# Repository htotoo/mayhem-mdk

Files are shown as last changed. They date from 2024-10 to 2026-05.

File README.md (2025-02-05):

# PortaPack Mayhem External Module Developer Kit "MDK"
This is the Developer Kit External Module for the [HackRF+PortaPack H4](https://github.com/portapack-mayhem/mayhem-firmware)

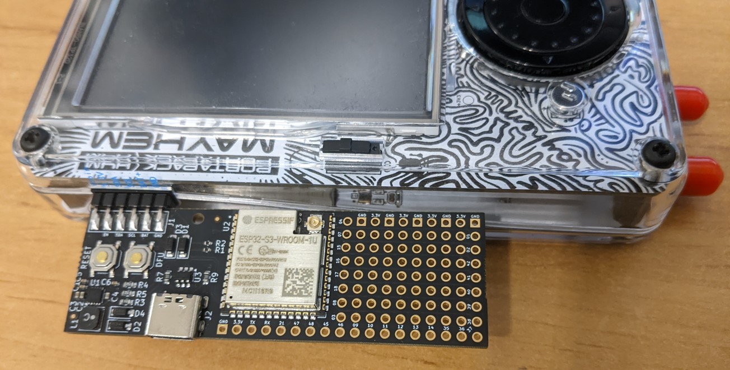
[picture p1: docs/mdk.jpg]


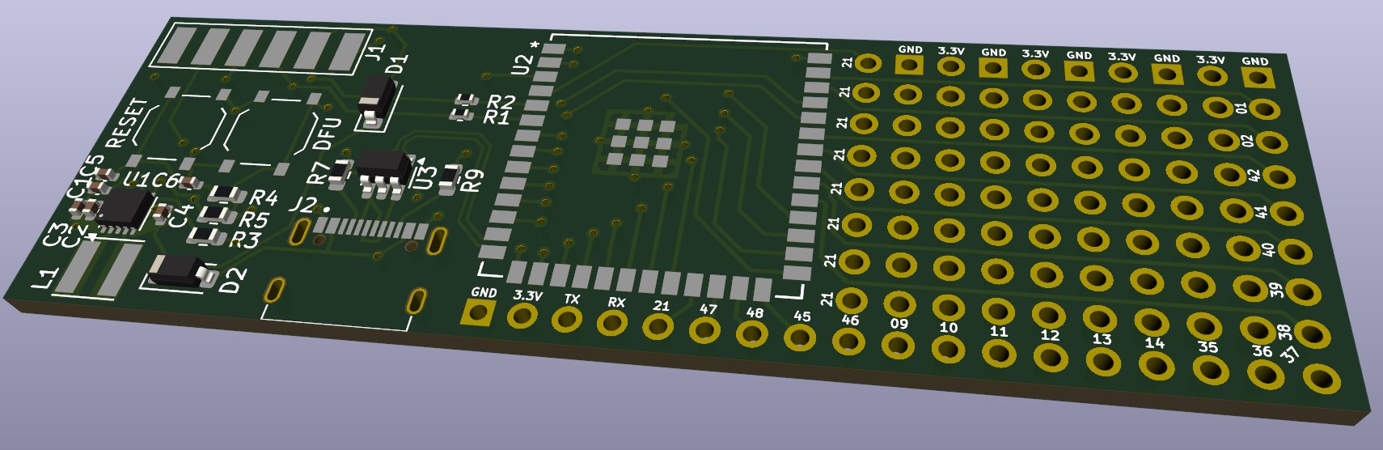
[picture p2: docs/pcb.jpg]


## How to get the hardware
All the design files are in the pcb folder. They are set up so you can let [JLCPCB](https://jlcpcb.com/) manufacture a few boards by using the files in pcb/production.

## How to compile
The software consists of two separate parts:
- The Standalone App that is uploaded and executed on the portapack.
  - This will be embedded in the the ESP32 firmware, so is required first.
  - The guide can be found [here](src/uart/Readme.md)
- The firmware for the ESP32-S3.
  - The guide can be found [here](src/portapack-external-module/README.md) 
  - Note: ESP-IDF version 5.4 introduced a breaking change in the I2C subsystem. So use the latest version of 5.3.

## How to use the example UART app
Once the Firmware is uploaded and the module is plugged into the Portapack, the UART app should appear in the Utilities menu.

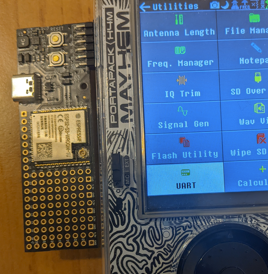
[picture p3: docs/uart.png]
uart app


The UART app will display any UART signal on pin 14.

## Schematics
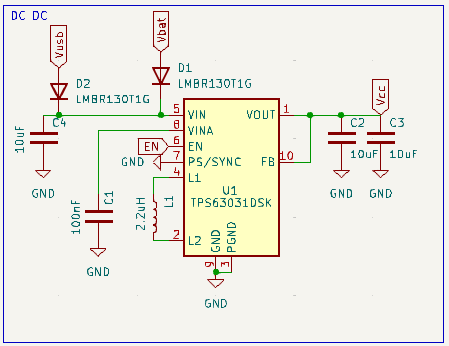
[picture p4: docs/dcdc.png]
dcdc


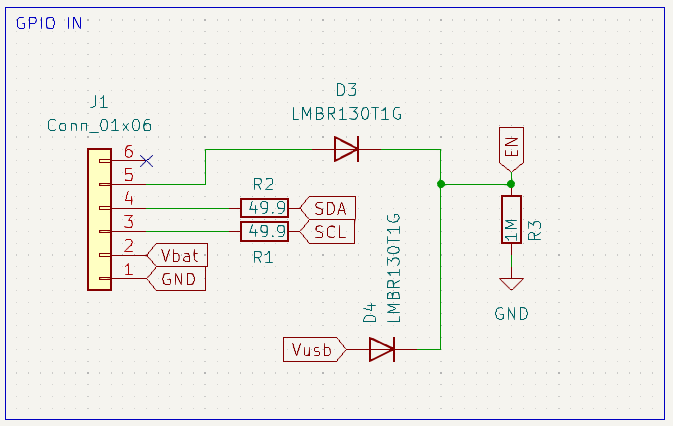
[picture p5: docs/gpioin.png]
gpioin


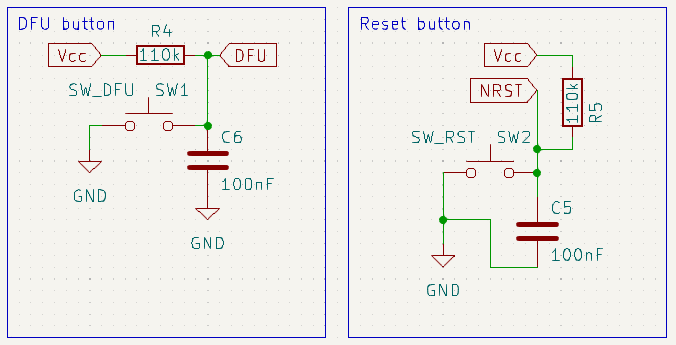
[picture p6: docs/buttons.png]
buttons


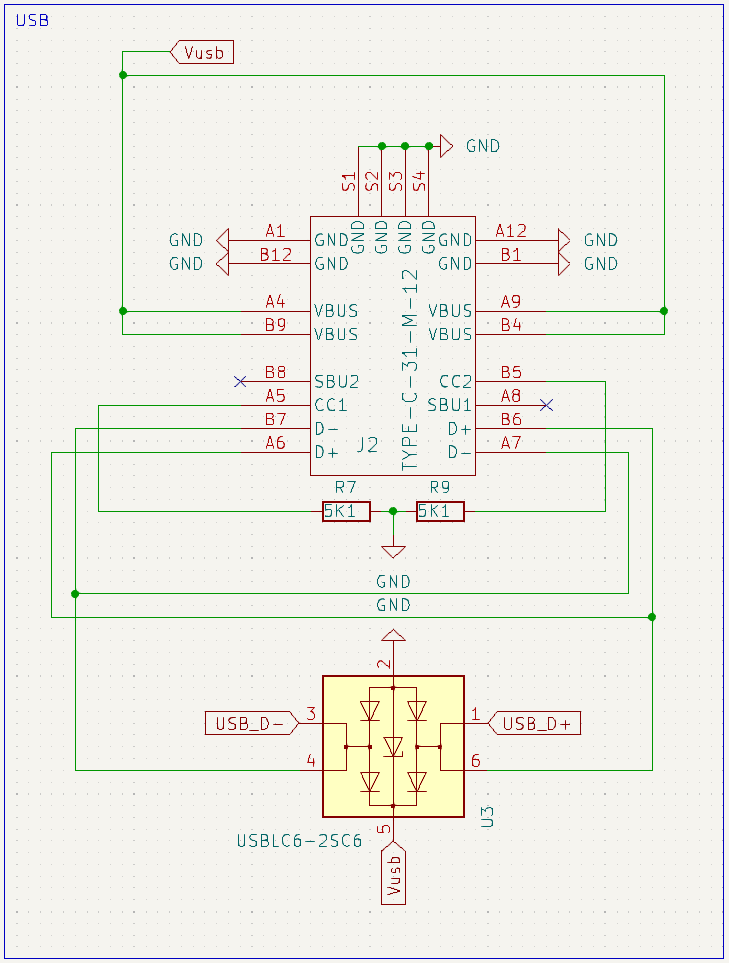
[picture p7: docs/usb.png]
usb


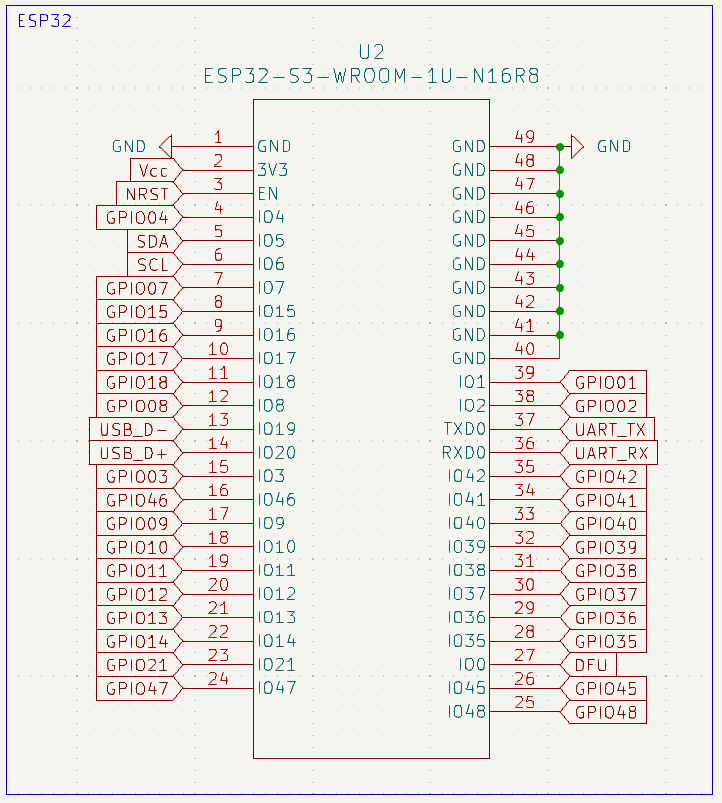
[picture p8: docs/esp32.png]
esp32


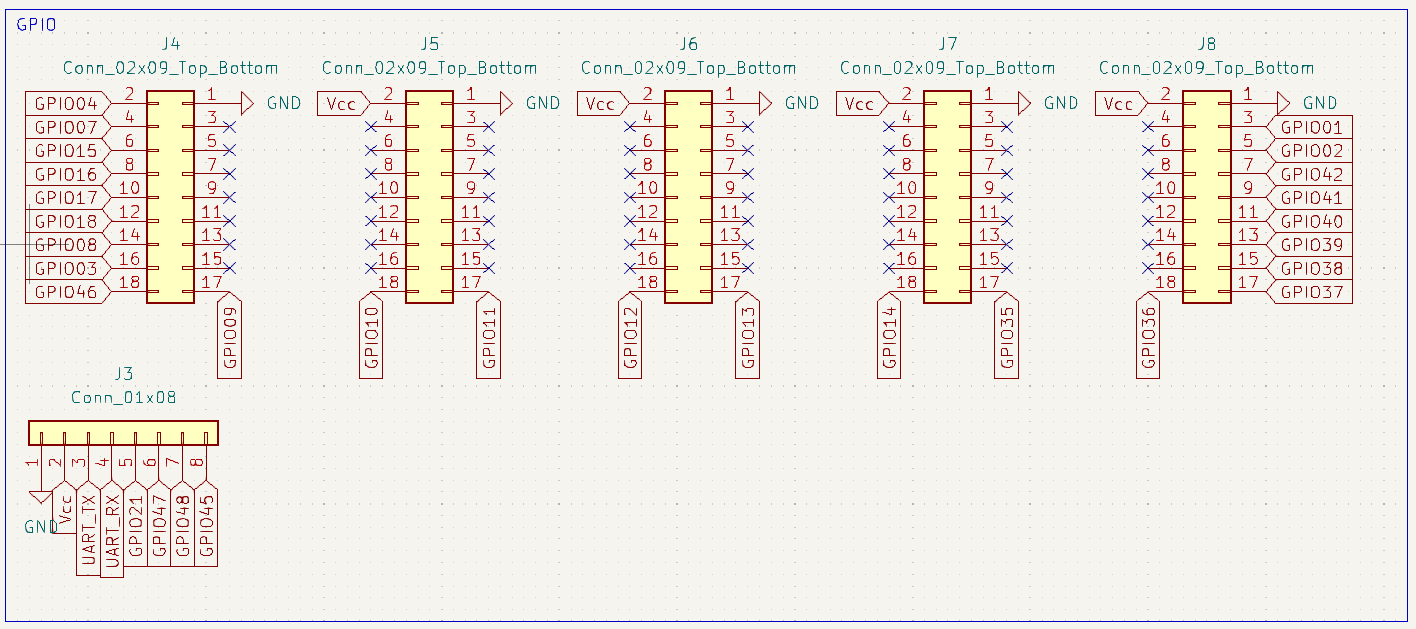
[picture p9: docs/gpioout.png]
gpioout


## Pinout
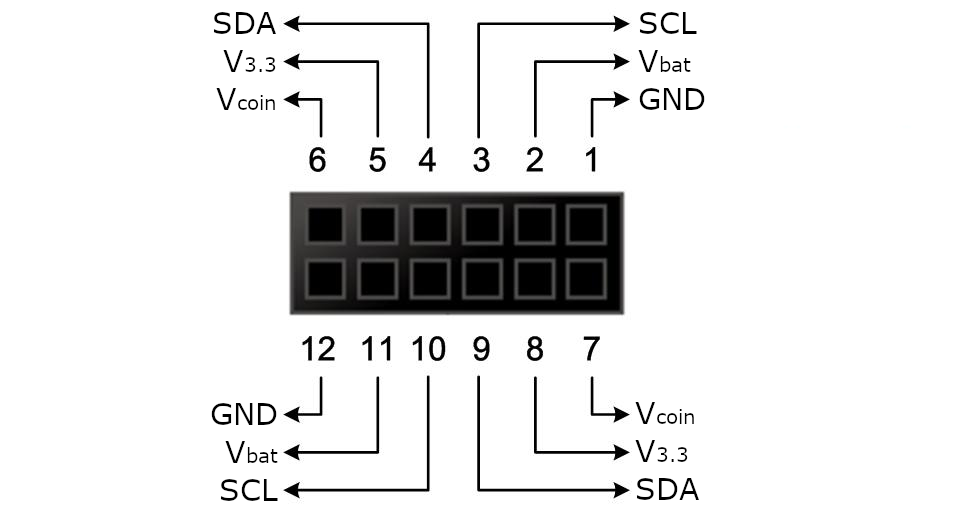
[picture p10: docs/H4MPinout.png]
pinout


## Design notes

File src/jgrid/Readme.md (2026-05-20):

# jgrid

This is a joke app that simulates "hacking" Grids (like power grids), and can power down nuclear plans.

It is only for fun and parody.

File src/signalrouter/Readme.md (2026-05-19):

# Signal router

The TX must wired to RX

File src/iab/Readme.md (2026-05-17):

# iab

Idle miner app, when you drill down, while each level is harder, so you'll need to buy upgrades.

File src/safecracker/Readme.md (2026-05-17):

# Safecracker game

Crack the safe by selecting the correct code for each slot. Time is ticking, and the signal is getting weaker and weaker.

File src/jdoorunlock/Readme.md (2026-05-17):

# jdoorunlock

This is a joke app that simulates "hacking" door locks and unlocking any door wirelessly.

It is only for fun and parody.

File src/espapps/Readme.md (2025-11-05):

# App manager for ESP32PP

# to build

cmake -DCMAKE_TOOLCHAIN_FILE=arm-none-eabi-toolchain.cmake -B build -S.
make -C build espapps

# build with docker
docker build -t arm-docker-build config
docker run --rm -v .:/src -w /src arm-docker-build bash -c "cmake -DCMAKE_TOOLCHAIN_FILE=config/arm-none-eabi-toolchain.cmake -B build -S."
docker run --rm -v .:/src -w /src arm-docker-build bash -c "make -C build -j3"

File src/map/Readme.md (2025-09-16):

# A test app to check if map ui is working in the standalone apps. 
Not used anywhere, just a test app

# Requirements
Like the mayhem-firmware a version of gcc-arm-none-eabi is required. See [Compile Firmware](https://github.com/portapack-mayhem/mayhem-firmware/wiki/Compile-firmware) on how to get started.

# to build

cmake -DCMAKE_TOOLCHAIN_FILE=../common/config/arm-none-eabi-toolchain.cmake -B build -S.
make -C build

# build with docker
docker build -t arm-docker-build ../common/config
docker run --rm -v .:/src -w /src arm-docker-build bash -c "cmake -DCMAKE_TOOLCHAIN_FILE=common/config/arm-none-eabi-toolchain.cmake -B build -S."
docker run --rm -v .:/src -w /src arm-docker-build bash -c "make -C build -j3"

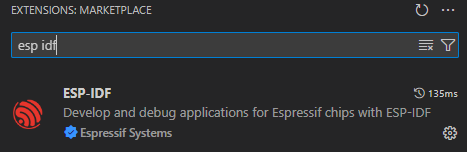
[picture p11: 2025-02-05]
src/portapack-external-module/espidf.png

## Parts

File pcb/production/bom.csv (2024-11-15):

Designator | Footprint | Quantity | Value | LCSC Part #
C1_5, C1_4, C1_3, C1_2, C1, C5_5, C5_4, C5_3, C5_2, C5, C6_5, C6_4, C6_3, C6_2, C6 | 0402 | 15 | 100nF | C1525
C2_5, C2_4, C2_3, C2_2, C2, C3_5, C3_4, C3_3, C3_2, C3, C4_5, C4_4, C4_3, C4_2, C4 | 0402 | 15 | 10uF | C15525
D1_5, D1_4, D1_3, D1_2, D1, D2_5, D2_4, D2_3, D2_2, D2, D3_5, D3_4, D3_3, D3_2, D3, D4_5, D4_4, D4_3, D4_2, D4 | D_SOD-123 | 20 | LMBR130T1G | C48974
J2_5, J2_4, J2_3, J2_2, J2 | TYPE-C-31-M-12 | 5 | TYPE-C-31-M-12 | C165948
L1_5, L1_4, L1_3, L1_2, L1 | L_Taiyo-Yuden_NR-40xx | 5 | 2.2uH | C515383
R1_5, R1_4, R1_3, R1_2, R1, R2_5, R2_4, R2_3, R2_2, R2 | 0402 | 10 | 49.9 | C25120
R3_5, R3_4, R3_3, R3_2, R3 | 0603 | 5 | 1M | C22935
R4_5, R4_4, R4_3, R4_2, R4, R5_5, R5_4, R5_3, R5_2, R5 | 0603 | 10 | 110k | C25805
R7_5, R7_4, R7_3, R7_2, R7, R9_5, R9_4, R9_3, R9_2, R9 | 0603 | 10 | 5K1 | C23186
SW1_5, SW1_4, SW1_3, SW1_2, SW1 | SW_Push_1P1T_XKB_TS-1187A | 5 | SW_DFU | C318884
SW2_5, SW2_4, SW2_3, SW2_2, SW2 | SW_Push_1P1T_XKB_TS-1187A | 5 | SW_RST | C318884
U1_5, U1_4, U1_3, U1_2, U1 | WSON-10-1EP_2.5x2.5mm_P0.5mm_EP1.2x2mm | 5 | TPS63031DSK | C15516
U2_5, U2_4, U2_3, U2_2, U2 | ESP32-S3-WROOM-1U_EXP | 5 | ESP32-S3-WROOM-1U-N16R8 | C3013946
U3_5, U3_4, U3_3, U3_2, U3 | SOT-23-6 | 5 | USBLC6-2SC6 | C2827654

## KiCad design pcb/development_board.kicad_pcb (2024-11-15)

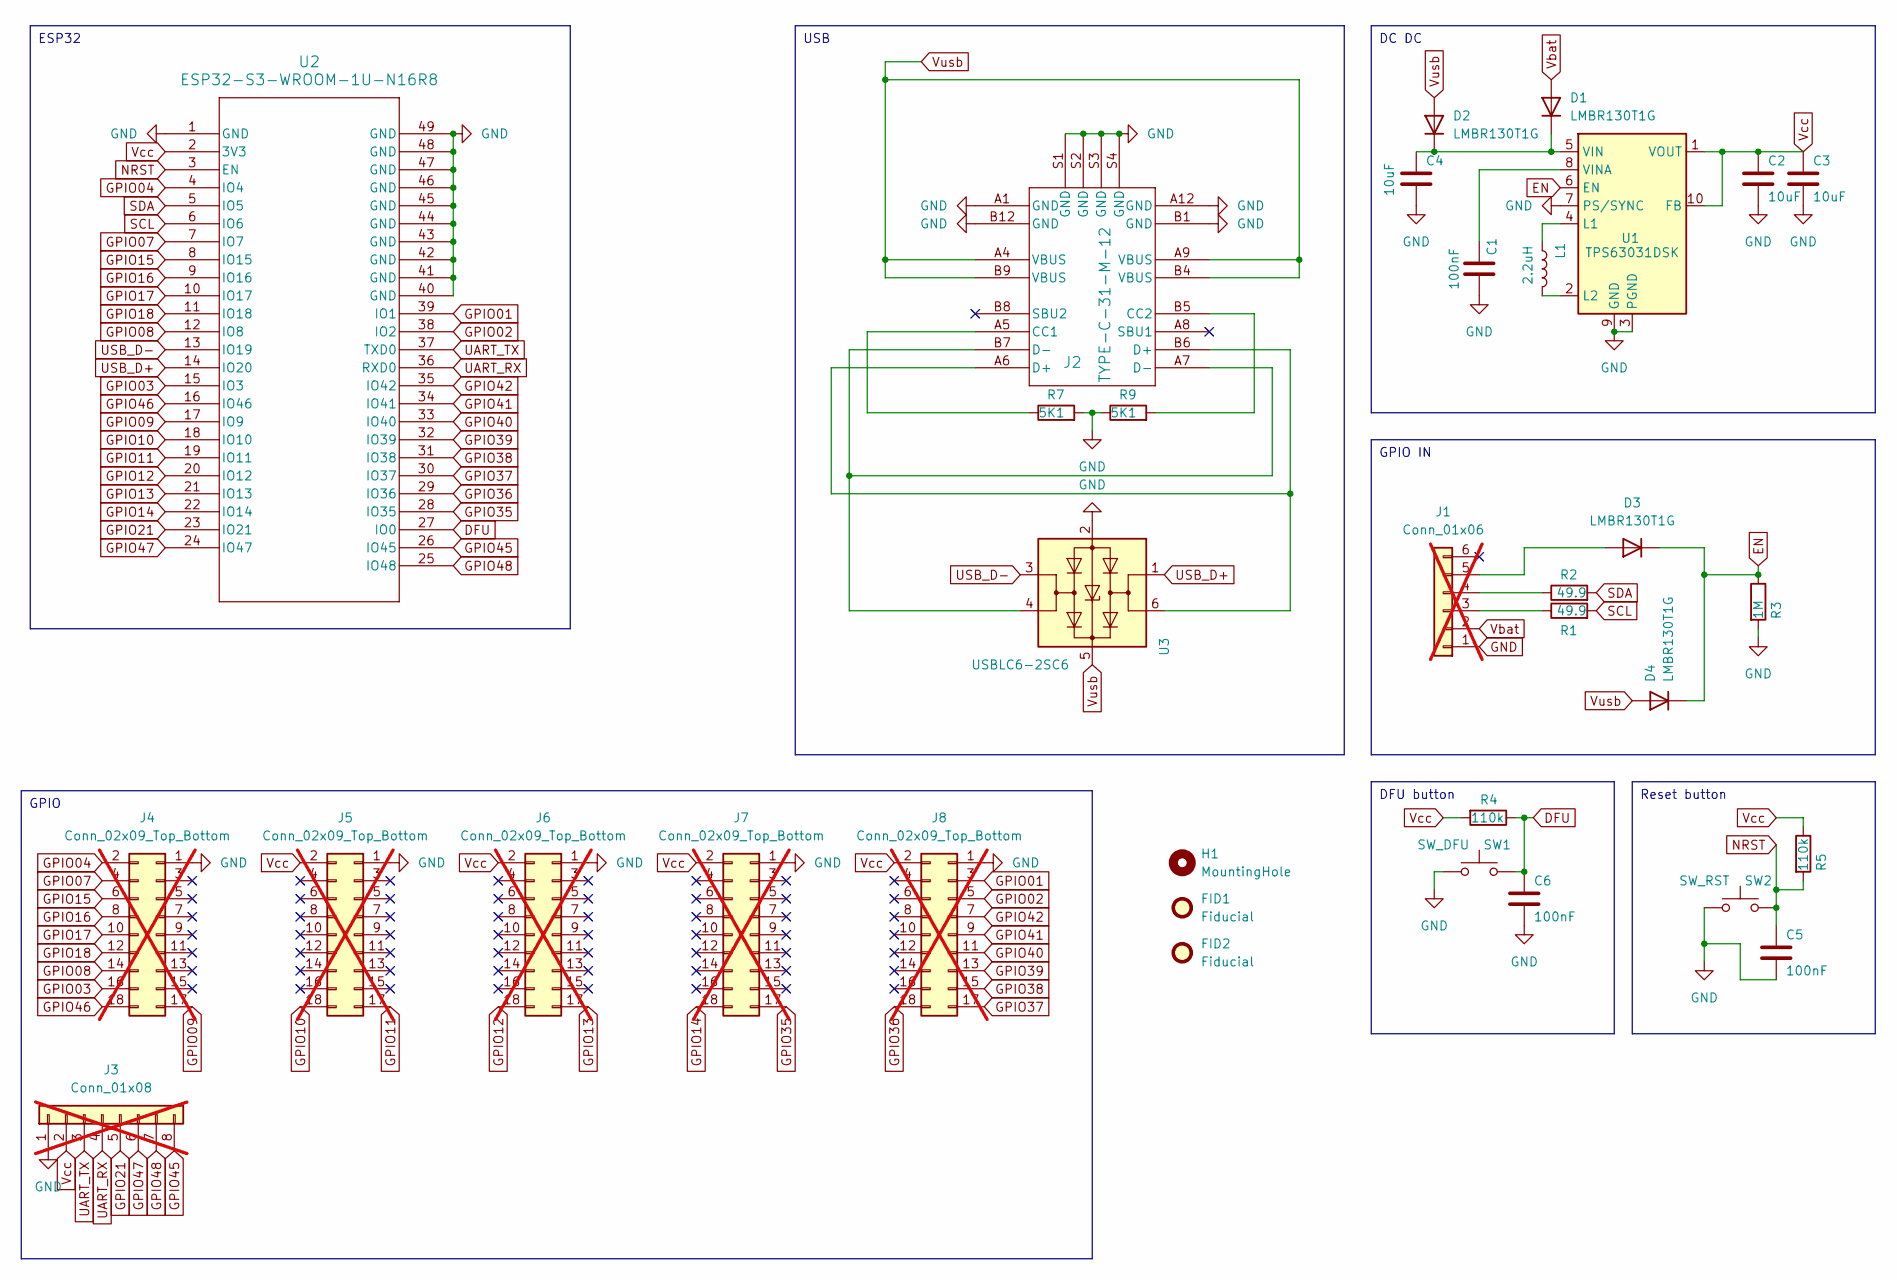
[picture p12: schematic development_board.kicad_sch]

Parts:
C1, C5, C6: 100nF; C_0402_1005Metric; Part CL05B104KO5NNNC; JLC 0402
C2, C3, C4: 10uF; C_0402_1005Metric; Part CL05A106MQ5NUNC; JLC 0402
D1, D2, D3, D4: LMBR130T1G; D_SOD-123; Part LMBR130T1G; JLC SOD-123
FID1, FID2: Fiducial; Fiducial_0.75mm_Mask1.5mm
H1: MountingHole; MountingHole_2mm
J1: Conn_01x06; External Module; not fitted
J2: TYPE-C-31-M-12; JLC SMD
J3: Conn_01x08; PinSocket_1x08_P2.54mm_Vertical; not fitted
J4, J5, J6, J7, J8: Conn_02x09_Top_Bottom; PinSocket_2x09_P2.54mm_Vertical; not fitted
L1: 2.2uH; L_Taiyo-Yuden_NR-40xx; Part NRS4010T2R2MDGGV; JLC SMD,4x4mm
R1, R2: 49.9; R_0402_1005Metric; Part 0402WGF499JTCE; JLC 0402
R3: 1M; R_0603_1608Metric; Part 0603WAF1004T5E; JLC 0603
R4, R5: 110k; R_0603_1608Metric; Part 0603WAF1103T5E; JLC 0603
R7, R9: 5K1; R_0603_1608Metric; Part 0603WAF5101T5E; JLC 0603
SW1: SW_DFU; SW_Push_1P1T_XKB_TS-1187A; Part TS-1187A-B-A-B; JLC SMD
SW2: SW_RST; SW_Push_1P1T_XKB_TS-1187A; Part TS-1187A-B-A-B; JLC SMD
U1: TPS63031DSK; WSON-10-1EP_2.5x2.5mm_P0.5mm_EP1.2x2mm; Part TPS63031DSKR; JLC SON-10-EP(2.5x2.5)
U2: ESP32-S3-WROOM-1U-N16R8; ESP32­S3­WROOM­1U_EXP; Part ESP32-S3-WROOM-1U-N16R8; JLC SMD,18x19.2mm
U3: USBLC6-2SC6; SOT-23-6; Part USBLC6-2SC6; JLC SOT-23-6

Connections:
DFU: C6.1, R4.1, SW1.2, U2.27 (IO0)
EN: D3.1 (K), D4.1 (K), R3.1, U1.6 (EN)
GND: C1.2, C2.2, C3.2, C4.2, C5.2, C6.2, J1.1, J2.A1 (GND), J2.A12 (GND), J2.B1 (GND), J2.B12 (GND), J2.S1 (GND), J2.S2 (GND), J2.S3 (GND), J2.S4 (GND), J3.1, J4.1, J5.1, J6.1, J7.1, J8.1, R3.2, R7.2, R9.1, SW1.1, SW2.1, U1.3 (PGND), U1.7 (PS/SYNC), U1.9 (GND), U1.11 (PGND), U2.1 (GND), U2.40 (GND), U2.41 (GND), U2.42 (GND), U2.43 (GND), U2.44 (GND), U2.45 (GND), U2.46 (GND), U2.47 (GND), U2.48 (GND), U2.49 (GND), U3.2 (GND)
GPIO01: J8.3, U2.39 (IO1)
GPIO02: J8.5, U2.38 (IO2)
GPIO03: J4.16, U2.15 (IO3)
GPIO04: J4.2, U2.4 (IO4)
GPIO07: J4.4, U2.7 (IO7)
GPIO08: J4.14, U2.12 (IO8)
GPIO09: J4.17, U2.17 (IO9)
GPIO10: J5.18, U2.18 (IO10)
GPIO11: J5.17, U2.19 (IO11)
GPIO12: J6.18, U2.20 (IO12)
GPIO13: J6.17, U2.21 (IO13)
GPIO14: J7.18, U2.22 (IO14)
GPIO15: J4.6, U2.8 (IO15)
GPIO16: J4.8, U2.9 (IO16)
GPIO17: J4.10, U2.10 (IO17)
GPIO18: J4.12, U2.11 (IO18)
GPIO21: J3.5, U2.23 (IO21)
GPIO35: J7.17, U2.28 (IO35)
GPIO36: J8.18, U2.29 (IO36)
GPIO37: J8.17, U2.30 (IO37)
GPIO38: J8.15, U2.31 (IO38)
GPIO39: J8.13, U2.32 (IO39)
GPIO40: J8.11, U2.33 (IO40)
GPIO41: J8.9, U2.34 (IO41)
GPIO42: J8.7, U2.35 (IO42)
GPIO45: J3.8, U2.26 (IO45)
GPIO46: J4.18, U2.16 (IO46)
GPIO47: J3.6, U2.24 (IO47)
GPIO48: J3.7, U2.25 (IO48)
NRST: C5.1, R5.2, SW2.2, U2.3 (EN)
unnamed: C4.1, D1.1 (K), D2.1 (K), U1.5 (VIN)
unnamed: D3.2 (A), J1.5
unnamed: J1.3, R1.1
unnamed: J1.4, R2.1
unnamed: J2.A5 (CC1), R7.1
unnamed: J2.B5 (CC2), R9.2
unnamed: J2.A6 (D+), J2.B6 (D+), U3.6 (I/O1)
unnamed: J2.A7 (D-), J2.B7 (D-), U3.4 (I/O2)
unnamed: L1.1, U1.4 (L1)
unnamed: L1.2, U1.2 (L2)
unnamed: C1.1, U1.8 (VINA)
SCL: R1.2, U2.6 (IO6)
SDA: R2.2, U2.5 (IO5)
UART_RX: J3.4, U2.36 (RXD0)
UART_TX: J3.3, U2.37 (TXD0)
USB_D+: U2.14 (IO20), U3.1 (I/O1)
USB_D-: U2.13 (IO19), U3.3 (I/O2)
Vbat: D1.2 (A), J1.2
Vcc: C2.1, C3.1, J3.2, J5.2, J6.2, J7.2, J8.2, R4.2, R5.1, U1.1 (VOUT), U1.10 (FB), U2.2 (3V3)
Vusb: D2.2 (A), D4.2 (A), J2.A4 (VBUS), J2.A9 (VBUS), J2.B4 (VBUS), J2.B9 (VBUS), U3.5 (VBUS)

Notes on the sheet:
GPIO IN
GPIO
USB
DFU button
ESP32
DC DC
Reset button

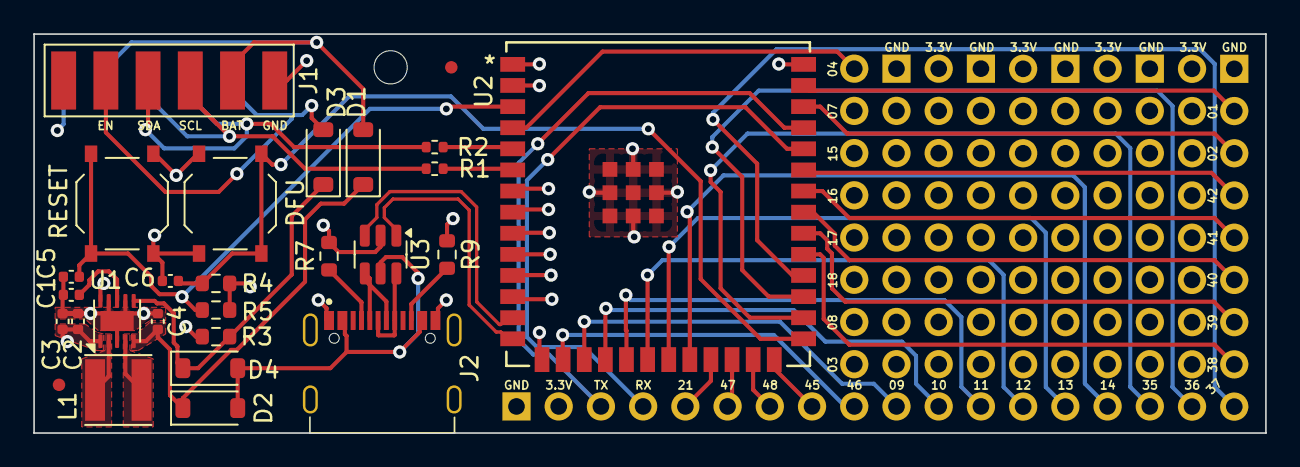
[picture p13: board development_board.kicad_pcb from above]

Board: 4 copper layers, 74.1 x 24.0 mm, 34 parts (0 on the bottom side), 53 nets.

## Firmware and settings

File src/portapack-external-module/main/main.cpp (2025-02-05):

#include <iostream>
#include <memory>
#include <cstring>
#include <vector>
#include <queue>
#include <algorithm>

#include "driver/i2c.h"
#include "driver/uart.h"
#include "uart_app.h"

#include "ppi2c/pp_handler.hpp"

static_assert(sizeof(uart_app) % 32 == 0, "app size must be multiple of 32 bytes. fill with 0s");

#define I2C_SLAVE_SDA_IO GPIO_NUM_6
#define I2C_SLAVE_SCL_IO GPIO_NUM_5

#define UART_RX GPIO_NUM_14

#define ESP_SLAVE_ADDR 0x51

#define LED_RED GPIO_NUM_46
#define LED_GREEN GPIO_NUM_0
#define LED_BLUE GPIO_NUM_45

// User commands
#define USER_COMMANDS_START 0x7F01
// UART specific commands
#define COMMAND_UART_REQUESTDATA_SHORT USER_COMMANDS_START
#define COMMAND_UART_REQUESTDATA_LONG (USER_COMMANDS_START + 1)
#define COMMAND_UART_BAUDRATE_INC (USER_COMMANDS_START + 2)
#define COMMAND_UART_BAUDRATE_DEC (USER_COMMANDS_START + 3)
#define COMMAND_UART_BAUDRATE_GET (USER_COMMANDS_START + 4)

void initialize_uart(uint32_t baudrate);
void deinitialize_uart();

uint32_t baudrate = 115200;

std::vector<uint32_t> baudrates = {50, 75, 110, 134, 150, 200, 300, 600,
                                   1200, 2400, 4800, 9600, 14400, 19200,
                                   28800, 38400, 57600, 115200, 230400,
                                   460800, 576000, 921600, 1843200, 3686400};

void initialize_gpio()
{
    gpio_install_isr_service(0);

    gpio_set_direction(LED_RED, GPIO_MODE_OUTPUT);
    gpio_set_direction(LED_GREEN, GPIO_MODE_OUTPUT);
    gpio_set_direction(LED_BLUE, GPIO_MODE_OUTPUT);

    gpio_set_level(LED_RED, 1);
    gpio_set_level(LED_GREEN, 1);
    gpio_set_level(LED_BLUE, 1);
}

std::queue<uint8_t> uart_queue;

#define BUF_SIZE (1024)

void initialize_uart(uint32_t baudrate)
{
    uart_config_t uart_config = {
        .baud_rate = (int)baudrate,
        .data_bits = UART_DATA_8_BITS,
        .parity = UART_PARITY_DISABLE,
        .stop_bits = UART_STOP_BITS_1,
        .flow_ctrl = UART_HW_FLOWCTRL_DISABLE,
        .rx_flow_ctrl_thresh = 0,
        .source_clk = UART_SCLK_DEFAULT,
        .flags = {.backup_before_sleep = 0}};

    int intr_alloc_flags = 0;

#if CONFIG_UART_ISR_IN_IRAM
    intr_alloc_flags = ESP_INTR_FLAG_IRAM;
#endif

    ESP_ERROR_CHECK(uart_driver_install(UART_NUM_1, BUF_SIZE * 2, 0, 0, NULL, intr_alloc_flags));
    ESP_ERROR_CHECK(uart_param_config(UART_NUM_1, &uart_config));
    ESP_ERROR_CHECK(uart_set_pin(UART_NUM_1, UART_PIN_NO_CHANGE, UART_RX, UART_PIN_NO_CHANGE, UART_PIN_NO_CHANGE));
}

void deinitialize_uart()
{
    ESP_ERROR_CHECK(uart_driver_delete(UART_NUM_1));
}

static void uart_task(void *arg)
{
    uint8_t *data = (uint8_t *)malloc(BUF_SIZE);
    while (true)
    {
        try
        {
            int len = uart_read_bytes(UART_NUM_1, data, (BUF_SIZE - 1), 20 / portTICK_PERIOD_MS);
            if (len != 0)
            {
                for (int i = 0; i < len; i++)
                    uart_queue.push(data[i]);
            }
        }
        catch (const std::exception &ex)
        {
            std::cout << "Exception: " << std::endl;
            std::cout << ex.what() << std::endl;
        }
    }
}

extern "C" void app_main(void)
{
    initialize_gpio();
    PPHandler::set_module_name("ESP32-S3-PPDEVKIT");
    PPHandler::set_module_version(1);
    PPHandler::add_app(uart_app, sizeof(uart_app));
    PPHandler::add_custom_command(COMMAND_UART_REQUESTDATA_SHORT, nullptr, [](pp_command_data_t data)
                                  {
                                      // 1 bit: more data available
                                      // 7 bit: data length [0 to 4]
                                      // 4 bytes: data from uart_queue optionally filled with 0xFF

                                      const int max_data_length = 4;
                                      data.data->resize(1 + max_data_length);

                                      uint8_t bytesToSend = uart_queue.size() > max_data_length ? max_data_length : uart_queue.size();
                                      bool moreData = uart_queue.size() > max_data_length ? 1 : 0;
                                      (*data.data)[0] = (bytesToSend & 0x7F) | (moreData << 7);

                                      for (int i = bytesToSend; i < max_data_length; i++)
                                          (*data.data)[i + 1] = 0xFF;

                                      for (int i = 0; i < bytesToSend; i++)
                                      {
                                          (*data.data)[i + 1] = uart_queue.front();
                                          uart_queue.pop();
                                      } });
    PPHandler::add_custom_command(COMMAND_UART_REQUESTDATA_LONG, nullptr, [](pp_command_data_t data)
                                  {
                                    // 1 bit: more data available
                                    // 7 bit: data length [0 to 4]
                                    // 4 bytes: data from uart_queue optionally filled with 0xFF

                                    // 1 bit: more data available
                                    // 7 bit: data length [0 to 127]
                                    // 127 bytes: data from uart_queue optionally filled with 0xFF

                                    const int max_data_length = 127;
                                    data.data->resize(1 + max_data_length);                                    

                                    uint8_t bytesToSend = uart_queue.size() > max_data_length ? max_data_length : uart_queue.size();
                                    bool moreData = uart_queue.size() > max_data_length ? 1 : 0;
                                    (*data.data)[0] = (bytesToSend & 0x7F) | (moreData << 7);

                                    for (int i = bytesToSend; i < max_data_length; i++)
                                        (*data.data)[i + 1] = 0xFF;

                                    for (int i = 0; i < bytesToSend; i++)
                                    {
                                        (*data.data)[i + 1] = uart_queue.front();
                                        uart_queue.pop();
                                    } });
    PPHandler::add_custom_command(COMMAND_UART_BAUDRATE_GET, nullptr, [](pp_command_data_t data)
                                  {
                                    data.data->resize(4);
                                    esp_rom_printf("COMMAND_UART_BAUDRATE_GET: %d\n", baudrate);
                                    *(uint32_t *)(*data.data).data() = baudrate; });

    PPHandler::add_custom_command(COMMAND_UART_BAUDRATE_INC, [](pp_command_data_t data)
                                  {
                                      deinitialize_uart();
                                      if (baudrate == baudrates.back())
                                          baudrate = baudrates.front();
                                      else
                                      {
                                          auto it = std::find(baudrates.begin(), baudrates.end(), baudrate);
                                          baudrate = *(it + 1);
                                      }
                                      esp_rom_printf("COMMAND_UART_BAUDRATE_INC: %d\n", baudrate);
                                      initialize_uart(baudrate); }, nullptr);

    PPHandler::add_custom_command(COMMAND_UART_BAUDRATE_DEC, [](pp_command_data_t data)
                                  {
                                    deinitialize_uart();
                                    if (baudrate == baudrates.front())
                                        baudrate = baudrates.back();
                                    else
                                    {
                                        auto it = std::find(baudrates.begin(), baudrates.end(), baudrate);
                                        baudrate = *(it - 1);
                                    }
                                    esp_rom_printf("COMMAND_UART_BAUDRATE_DEC: %d\n", baudrate);

                                    initialize_uart(baudrate); }, nullptr);
	PPHandler::init(I2C_SLAVE_SDA_IO, I2C_SLAVE_SCL_IO, ESP_SLAVE_ADDR);
    initialize_uart(baudrate);
    xTaskCreate(uart_task, "uart_task", 1024 * 2, (void *)0, 10, NULL);
    std::cout << "[PP MDK] PortaPack - Module Develoment Kit is ready." << std::endl;
}

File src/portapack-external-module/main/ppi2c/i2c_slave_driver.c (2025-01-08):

/*
   Copyright 2024 Unicom Engineering, all rights reserved

   Licensed under the Apache License, Version 2.0 (the "License");
   you may not use this file except in compliance with the License.
   You may obtain a copy of the License at

       http://www.apache.org/licenses/LICENSE-2.0

   Unless required by applicable law or agreed to in writing, software
   distributed under the License is distributed on an "AS IS" BASIS,
   WITHOUT WARRANTIES OR CONDITIONS OF ANY KIND, either express or implied.
   See the License for the specific language governing permissions and
   limitations under the License.

   Note to users: this was tested using ESP-IDF version 5.3.1, and the Esp32s2
   chip. It has some calls that are Esp32-S2 specific, because the HAL does not
   support certain features that are supported by the hardware. Therefore, you
   may have to adjust some calls to get this to work with your device. Either
   use HAL functions that support the calls, or rewrite using your device's
   registers. Contributions to get this ported to other devices are welcome!

   Much of the setup is copied from the existing slave driver. I'm not sure
   exactly what each thing does, but I tried to copy all of the needed calls
   from i2c_common.c

   Also, I did not spend a lot of time on configuration, I mostly just
   supported our use case. Pull requests to add configuration options are also
   welcome!
 */
#include <sys/param.h>
#include "i2c_slave_driver.h"
#include "esp_attr.h"
#include "esp_intr_types.h"
#include "hal/i2c_hal.h"
#include "driver/gpio.h"
#include "soc/io_mux_reg.h"
#include "esp_private/gpio.h"
#include "esp_private/periph_ctrl.h"
#include "esp_heap_caps.h"
#include "sdkconfig.h" // for switching on target types, until hal is fixed.
#define LOG_LOCAL_LEVEL ESP_LOG_INFO
#include "esp_log.h"
#include "esp_check.h"

static const char *TAG = "i2c.unicom_slave";

typedef struct {
    i2c_slave_device_t user_dev;
    int portNum;
    i2c_slave_callback_fn callback;
    intr_handle_t intr;
    gpio_num_t scl;
    gpio_num_t sda;
    i2c_hal_context_t hal;
    bool allocated; // is this device used
} i2c_slave_dev_private_t;

static i2c_slave_dev_private_t i2cdev[2] = {0};

static IRAM_ATTR void s_i2c_reset_buffer(i2c_slave_dev_private_t* i2c_slave) {
    i2c_slave->user_dev.bufstart = 0;
    i2c_slave->user_dev.bufend = 0;
}


static esp_err_t s_hp_i2c_pins_config(i2c_slave_dev_private_t* handle)
{
    int port_id = handle->portNum;

    // SDA pin configurations
    gpio_config_t sda_conf = {
        .intr_type = GPIO_INTR_DISABLE,
        .mode = GPIO_MODE_INPUT_OUTPUT_OD,
        .pull_down_en = false,
        .pull_up_en = GPIO_PULLUP_ENABLE,
        .pin_bit_mask = 1ULL << handle->sda,
    };
    ESP_RETURN_ON_ERROR(gpio_set_level(handle->sda, 1), TAG, "i2c sda pin set level failed");
    ESP_RETURN_ON_ERROR(gpio_config(&sda_conf), TAG, "config GPIO failed");
    gpio_func_sel(handle->sda, PIN_FUNC_GPIO);
    esp_rom_gpio_connect_out_signal(handle->sda, i2c_periph_signal[port_id].sda_out_sig, 0, 0);
    esp_rom_gpio_connect_in_signal(handle->sda, i2c_periph_signal[port_id].sda_in_sig, 0);

    // SCL pin configurations
    gpio_config_t scl_conf = {
        .intr_type = GPIO_INTR_DISABLE,
        .mode = GPIO_MODE_INPUT_OUTPUT_OD,
        .pull_down_en = false,
        .pull_up_en =  GPIO_PULLUP_ENABLE,
        .pin_bit_mask = 1ULL << handle->scl,
    };
    ESP_RETURN_ON_ERROR(gpio_set_level(handle->scl, 1), TAG, "i2c scl pin set level failed");
    ESP_RETURN_ON_ERROR(gpio_config(&scl_conf), TAG, "config GPIO failed");
    gpio_func_sel(handle->scl, PIN_FUNC_GPIO);
    esp_rom_gpio_connect_out_signal(handle->scl, i2c_periph_signal[port_id].scl_out_sig, 0, 0);
    esp_rom_gpio_connect_in_signal(handle->scl, i2c_periph_signal[port_id].scl_in_sig, 0);

    return ESP_OK;
}

static IRAM_ATTR void s_i2c_handle_rx_fifo_wm(i2c_slave_dev_private_t* i2c_slave)
{
    // read all data out of the rx fifo queue.
    i2c_hal_context_t *hal = &i2c_slave->hal;
    i2c_slave_device_t *s = &i2c_slave->user_dev;
    // can't be in send mode here.
    uint32_t rx_fifo_cnt;
    i2c_ll_get_rxfifo_cnt(hal->dev, &rx_fifo_cnt);
    uint32_t fifo_cnt_rd = MIN(sizeof(s->buffer) - s->bufend, rx_fifo_cnt);
    if(fifo_cnt_rd > 0) {
        ESP_ERROR_CHECK(s->state == I2C_STATE_SEND ? ESP_ERR_INVALID_STATE : ESP_OK);
        i2c_ll_read_rxfifo(hal->dev, s->buffer + s->bufend, fifo_cnt_rd);
        s->bufend += fifo_cnt_rd;
        s->state = I2C_STATE_RECV;
    }

    if(rx_fifo_cnt > fifo_cnt_rd)
    {
        // throw away additional bytes, we don't have a place to put them
        i2c_ll_rxfifo_rst(hal->dev);
    }
}

static IRAM_ATTR void s_i2c_handle_complete(i2c_slave_dev_private_t* i2c_slave)
{
    i2c_hal_context_t *hal = &i2c_slave->hal;
    i2c_slave_device_t *s = &i2c_slave->user_dev;
    // check if we have received any data. If so, this is an rx complete
    if(s->state == I2C_STATE_SEND)
    {
        // sending, check to see if there were bytes that didn't get sent.
        uint32_t tx_fifo_len;
        i2c_ll_get_txfifo_len(hal->dev, &tx_fifo_len);
        tx_fifo_len = SOC_I2C_FIFO_LEN - tx_fifo_len;
        if(tx_fifo_len > 0)
        {
            s->bufstart -= tx_fifo_len;
            // clear the fifo
            i2c_ll_txfifo_rst(hal->dev);
        }
    }
    else
    {
        // read all remaining fifo data
        s_i2c_handle_rx_fifo_wm(i2c_slave);
    }
    if(s->state != I2C_STATE_IDLE)
        i2c_slave->callback(s, I2C_CALLBACK_DONE);

    // reset the state of the slave device, it's about to go idle.
    i2c_ll_slave_disable_tx_it(hal->dev);
    s_i2c_reset_buffer(i2c_slave);
    s->state = I2C_STATE_IDLE;
}

static IRAM_ATTR void s_i2c_handle_tx_fifo_wm(i2c_slave_dev_private_t* i2c_slave)
{
    i2c_hal_context_t *hal = &i2c_slave->hal;
    i2c_slave_device_t *s = &i2c_slave->user_dev;
    uint32_t tx_fifo_rem;
    i2c_ll_get_txfifo_len(hal->dev, &tx_fifo_rem);
    uint8_t size = s->bufend - s->bufstart;
    if(size > tx_fifo_rem)
    {
        size = tx_fifo_rem;
    }
    if(size == 0) {
        // disable the interrupt, there is no data left to send
        i2c_ll_slave_disable_tx_it(hal->dev);
    } else {
        ESP_ERROR_CHECK(s->state == I2C_STATE_SEND ? ESP_OK : ESP_ERR_INVALID_STATE);
        i2c_ll_write_txfifo(hal->dev, s->buffer + s->bufstart, size);
        s->bufstart += size;
        i2c_ll_slave_clear_stretch(hal->dev);
        if(s->bufstart == s->bufend) // no more data to send
            i2c_ll_slave_disable_tx_it(hal->dev);
    }
}
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

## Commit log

2024-10-20 fix typo, add IRQ warning
    [main.cpp]
2024-11-06 added pcb design for mdk
    [development_board.kicad_pcb, development_board.kicad_sch]
2024-11-06 fixed labels
    [development_board.kicad_pcb]
2024-11-06 fixed enable when running only on usb
    [development_board.kicad_pcb, development_board.kicad_sch]
2024-11-06 fixed parts selection
    [development_board.kicad_sch]
2024-11-08 I2C shell
2024-11-15 added panelized pcb
    [bom.csv, development_board.kicad_pcb, development_board.kicad_sch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]
2025-01-04 updated i2c slave driver
2025-02-05 updated i2c pins
2025-02-05 added uart app info
2025-10-29 aboutrain reworked to new nav format
    [aboutrain.hpp]
2025-10-29 about memleak, and map rework
    [aboutrain.hpp]
2026-05-18 fix text of blastzone
    [blastzone.hpp]
2026-05-18 fixed infinite jump game
    [infjump.hpp]
2026-05-20 pos fix of jgrid
    [jgrid.hpp]
